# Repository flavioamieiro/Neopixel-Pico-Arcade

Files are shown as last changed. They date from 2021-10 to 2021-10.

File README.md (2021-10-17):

The Neopixel Pico Arcade is a simple mini game with LEDs for a screen and
controlled by an NES controller.

It's built around the [RP2040
stamp](https://www.solder.party/rp2040_stamp_datasheet.pdf) designed by
@arturo182.

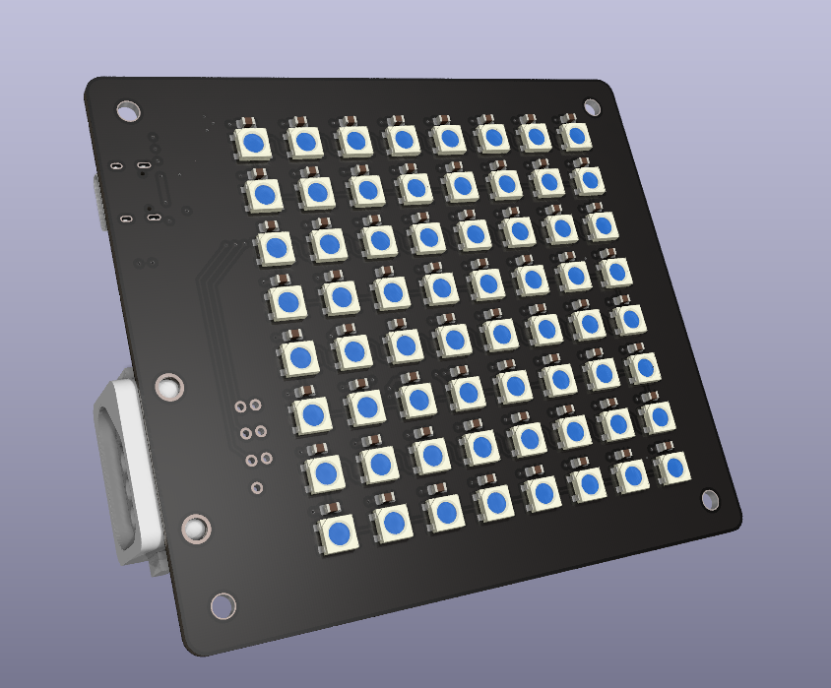
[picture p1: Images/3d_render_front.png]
PCB 3D render front

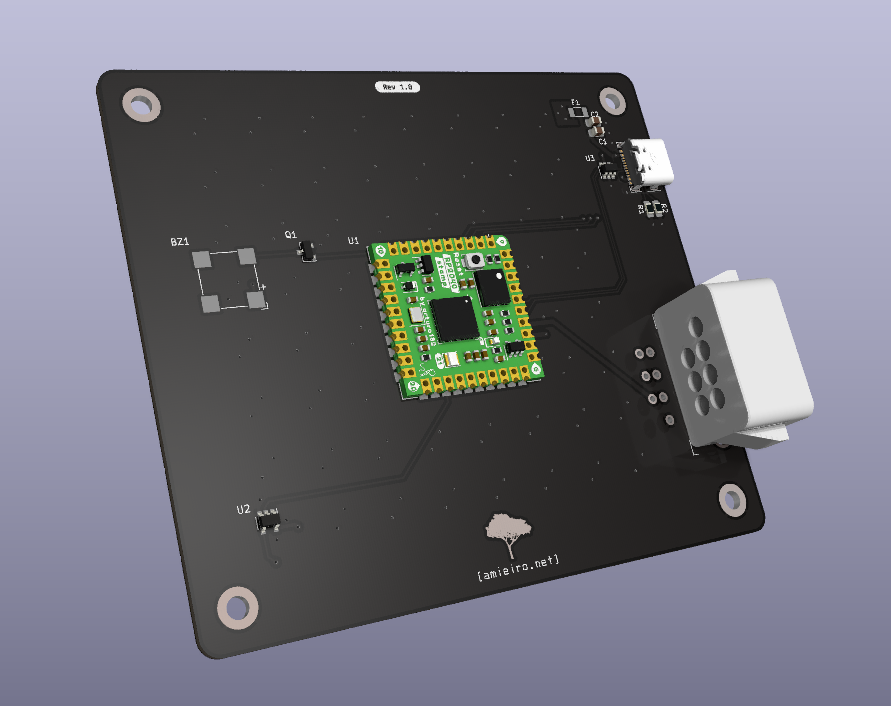
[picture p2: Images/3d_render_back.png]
PCB 3D render back


This source describes Open Hardware and is licensed under the CERN-OHL-S v2.
You may redistribute and modify this source and make products using it under
the terms of the [CERN-OHL-S v2](https://ohwr.org/cern_ohl_s_v2.txt).

Source location: https://github.com/flavioamieiro/Neopixel-Pico-Arcade

As per CERN-OHL-S v2 section 4, should You produce hardware based on this
source, You must where practicable maintain the Source Location visible on the
external case of the Gizmo or other products you make using this source.

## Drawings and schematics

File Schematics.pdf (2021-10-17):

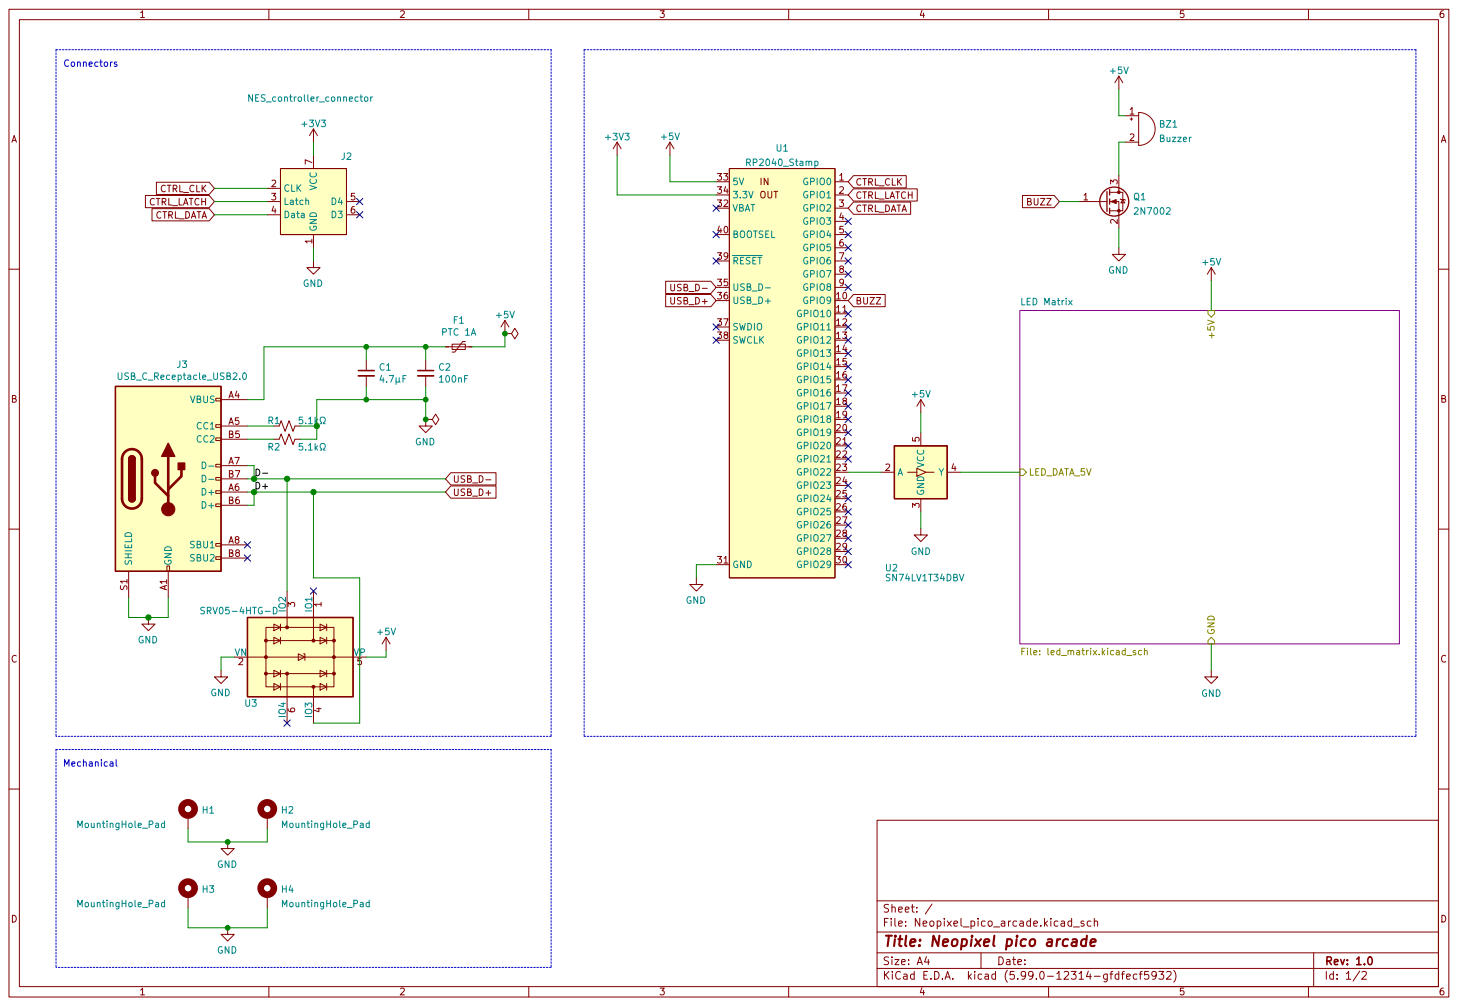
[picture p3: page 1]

File: Neopixel_pico_arcade.kicad_sch Sheet: /
Id: 1/2 Title: Neopixel pico arcade

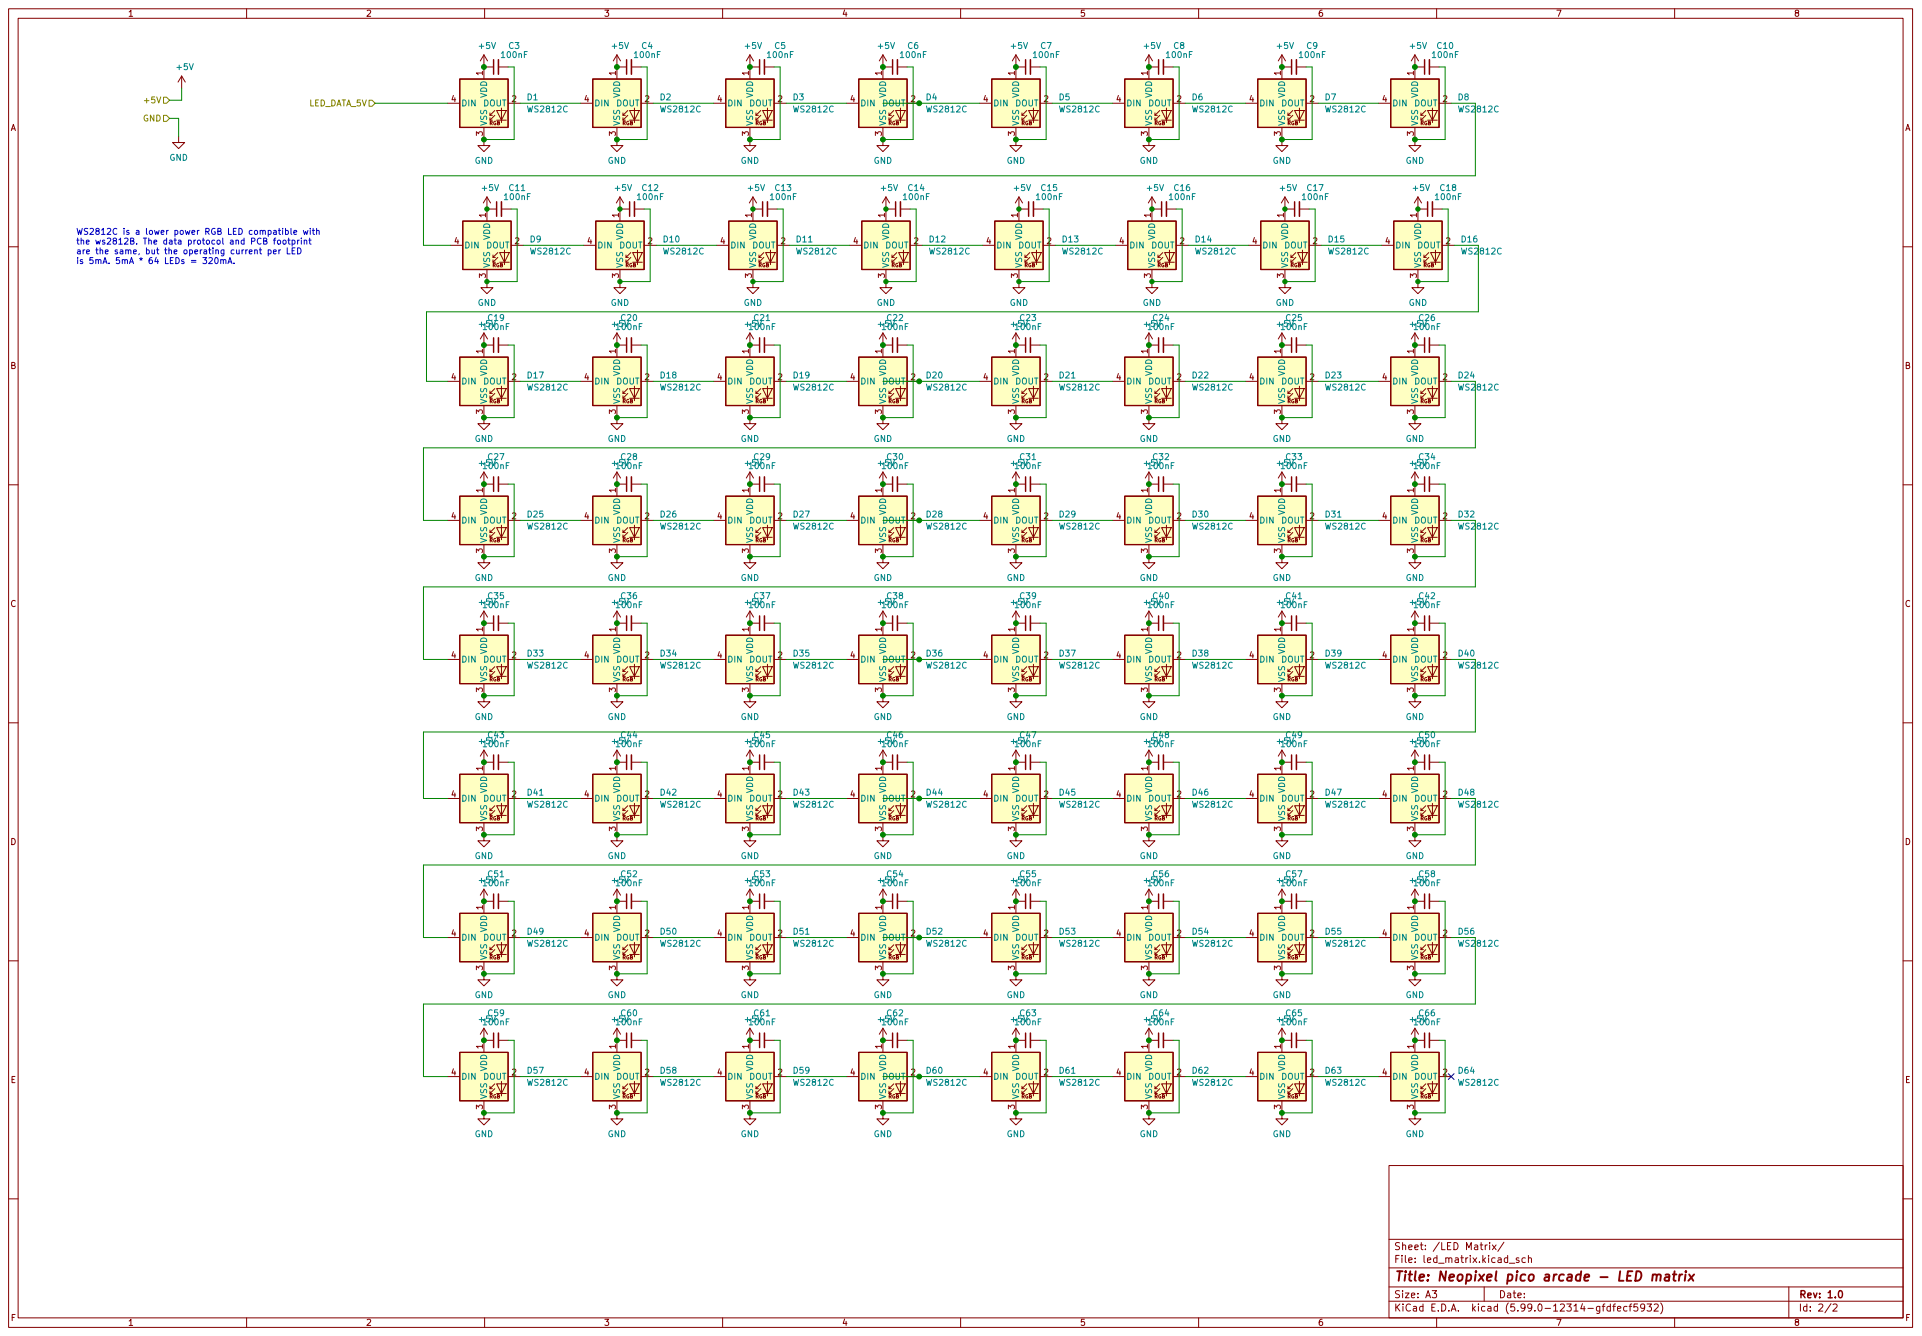
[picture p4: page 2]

LED_DATA_5V +5V GND WS2812C is a lower power RGB LED compatible with

the ws2812B. The data protocol and PCB footprint
are the same, but the operating current per LED
is 5mA. 5mA * 64 LEDs = 320mA.

File: led_matrix.kicad_sch Sheet: /LED Matrix/
Id: 2/2 Title: Neopixel pico arcade - LED matrix

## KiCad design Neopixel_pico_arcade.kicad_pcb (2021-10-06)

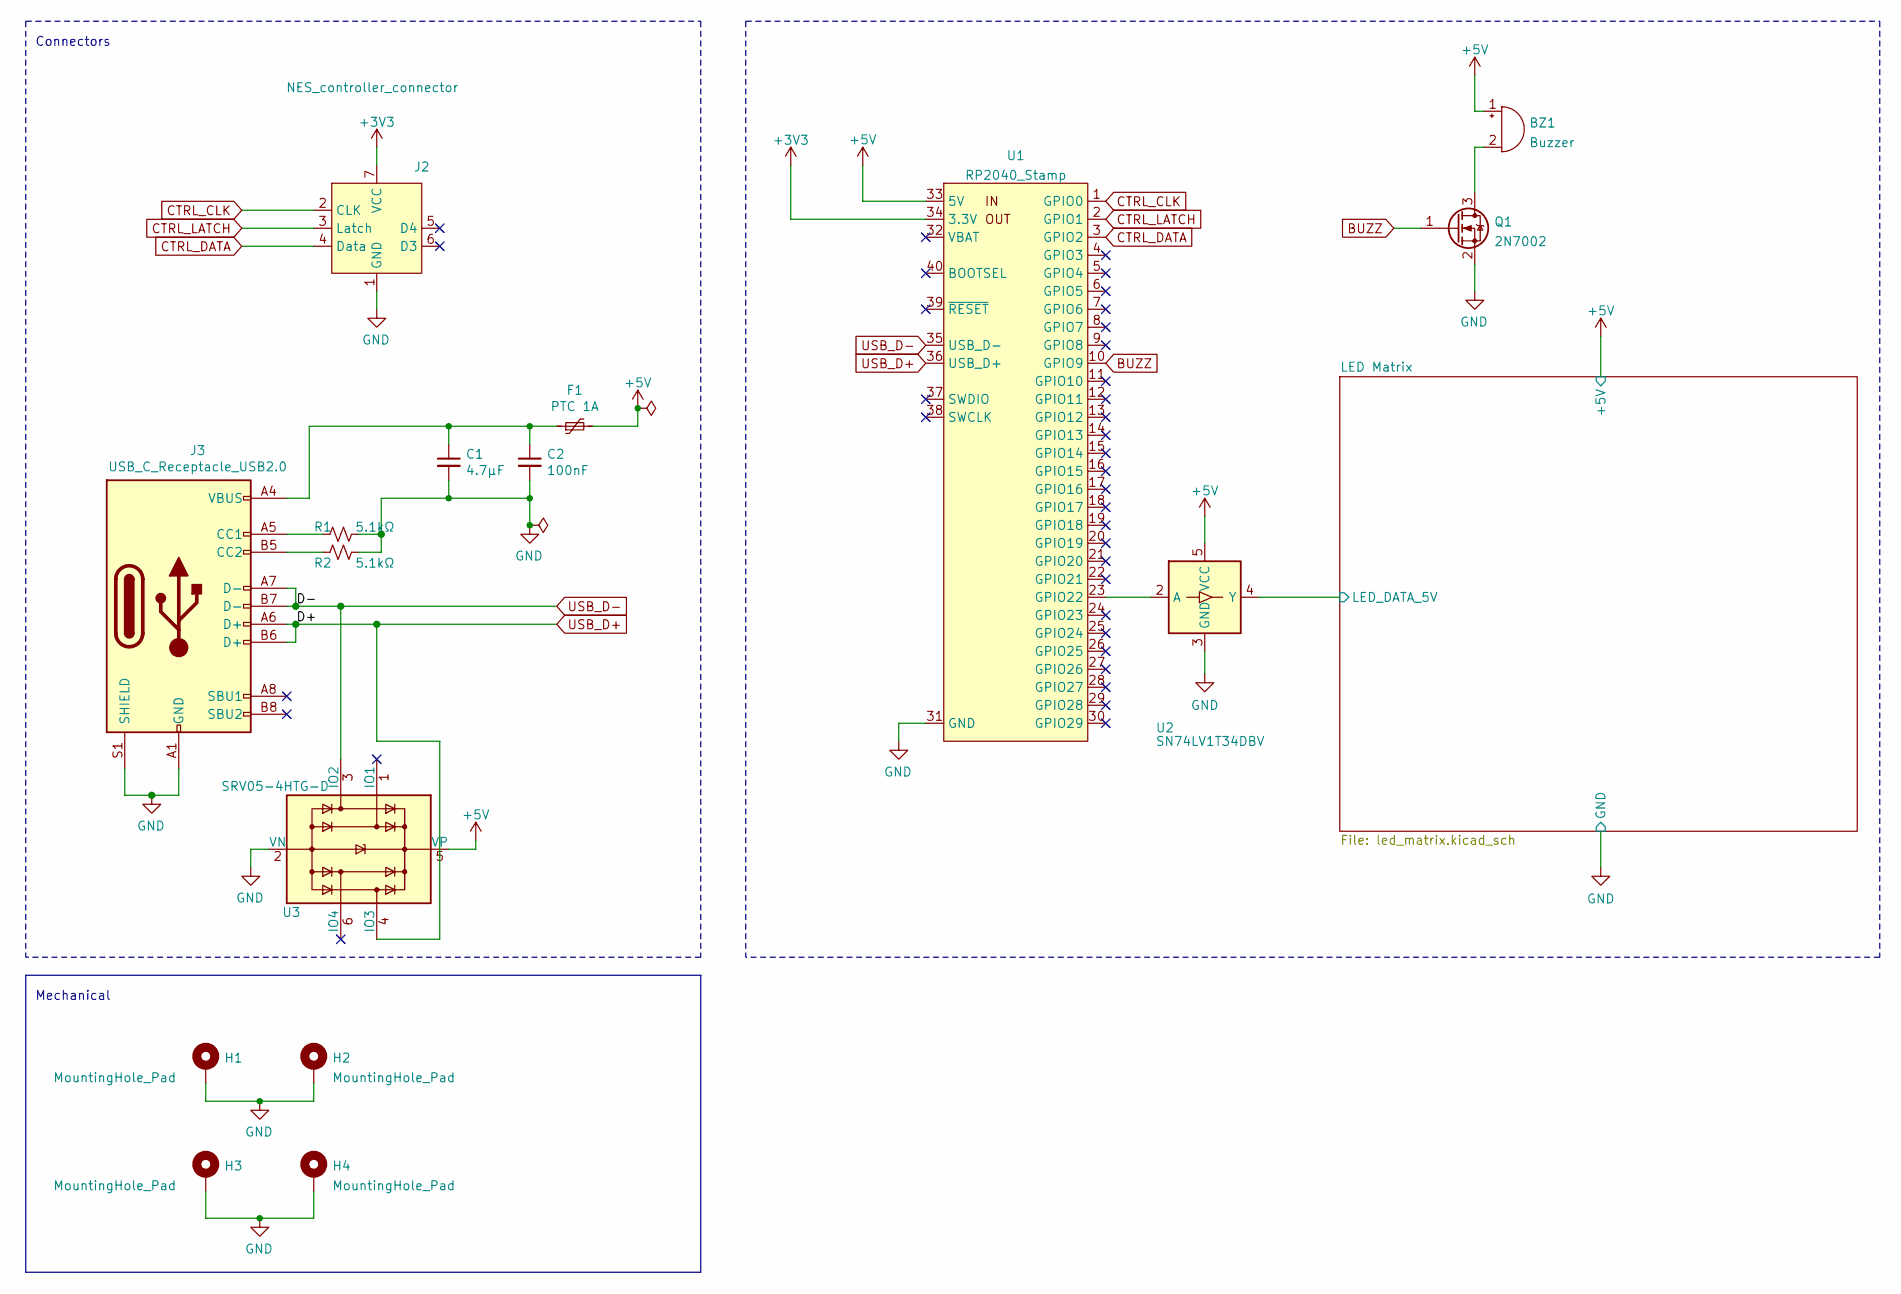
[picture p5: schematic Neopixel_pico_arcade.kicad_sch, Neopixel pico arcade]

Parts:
BZ1: Buzzer; MagneticBuzzer_CUI_CMT-8504-100-SMT
C1: 4.7µF; C_0805_2012Metric_Pad1.18x1.45mm_HandSolder
C2: 100nF; C_0805_2012Metric_Pad1.18x1.45mm_HandSolder
F1: PTC 1A; Belfuse_0ZCJ
H1, H2, H3, H4: MountingHole_Pad; MountingHole_3.2mm_M3_ISO7380_Pad_TopOnly
J2: NES_controller_connector; NES_Controller_connector
J3: USB_C_Receptacle_USB2.0; USB_C_Receptacle_USB_2_GTC_USB4105
Q1: 2N7002; SOT-23
R1, R2: 5.1kΩ; R_0805_2012Metric_Pad1.20x1.40mm_HandSolder
U1: RP2040_Stamp; RP2040_Stamp_SMD
U2: SN74LV1T34DBV; SOT-23-5
U3: SRV05-4HTG-D; SOT-23-6; MPN SRV05-4HTG-D

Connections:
+3V3: J2.7 (VCC), U1.34 (3.3V)
+5V: BZ1.1 (-), F1.2, U1.33 (5V), U2.5 (VCC), U3.5 (VP); also elsewhere on the board
/LED Matrix/LED_DATA_5V: U2.4 (Y); also elsewhere on the board
BUZZ: Q1.1 (G), U1.10 (GPIO9)
CTRL_CLK: J2.2 (CLK), U1.1 (GPIO0)
CTRL_DATA: J2.4 (Data), U1.3 (GPIO2)
CTRL_LATCH: J2.3 (Latch), U1.2 (GPIO1)
GND: C1.2, C2.2, H1.1, H2.1, H3.1, H4.1, J2.1 (GND), J3.A1 (GND), J3.A12 (GND), J3.B1 (GND), J3.B12 (GND), J3.S1 (SHIELD), Q1.2 (S), R1.2, R2.2, U1.31 (GND), U2.3 (GND), U3.2 (VN); also elsewhere on the board
unnamed: BZ1.2 (+), Q1.3 (D)
unnamed: C1.1, C2.1, F1.1, J3.A4 (VBUS), J3.A9 (VBUS), J3.B4 (VBUS), J3.B9 (VBUS)
unnamed: J3.A5 (CC1), R1.1
unnamed: J3.B5 (CC2), R2.1
unnamed: U1.23 (GPIO22), U2.2 (A)
USB_D+: J3.A6 (D+), J3.B6 (D+), U1.36 (USB_D+), U3.4 (IO3)
USB_D-: J3.A7 (D-), J3.B7 (D-), U1.35 (USB_D-), U3.3 (IO2)

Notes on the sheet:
Mechanical
Connectors

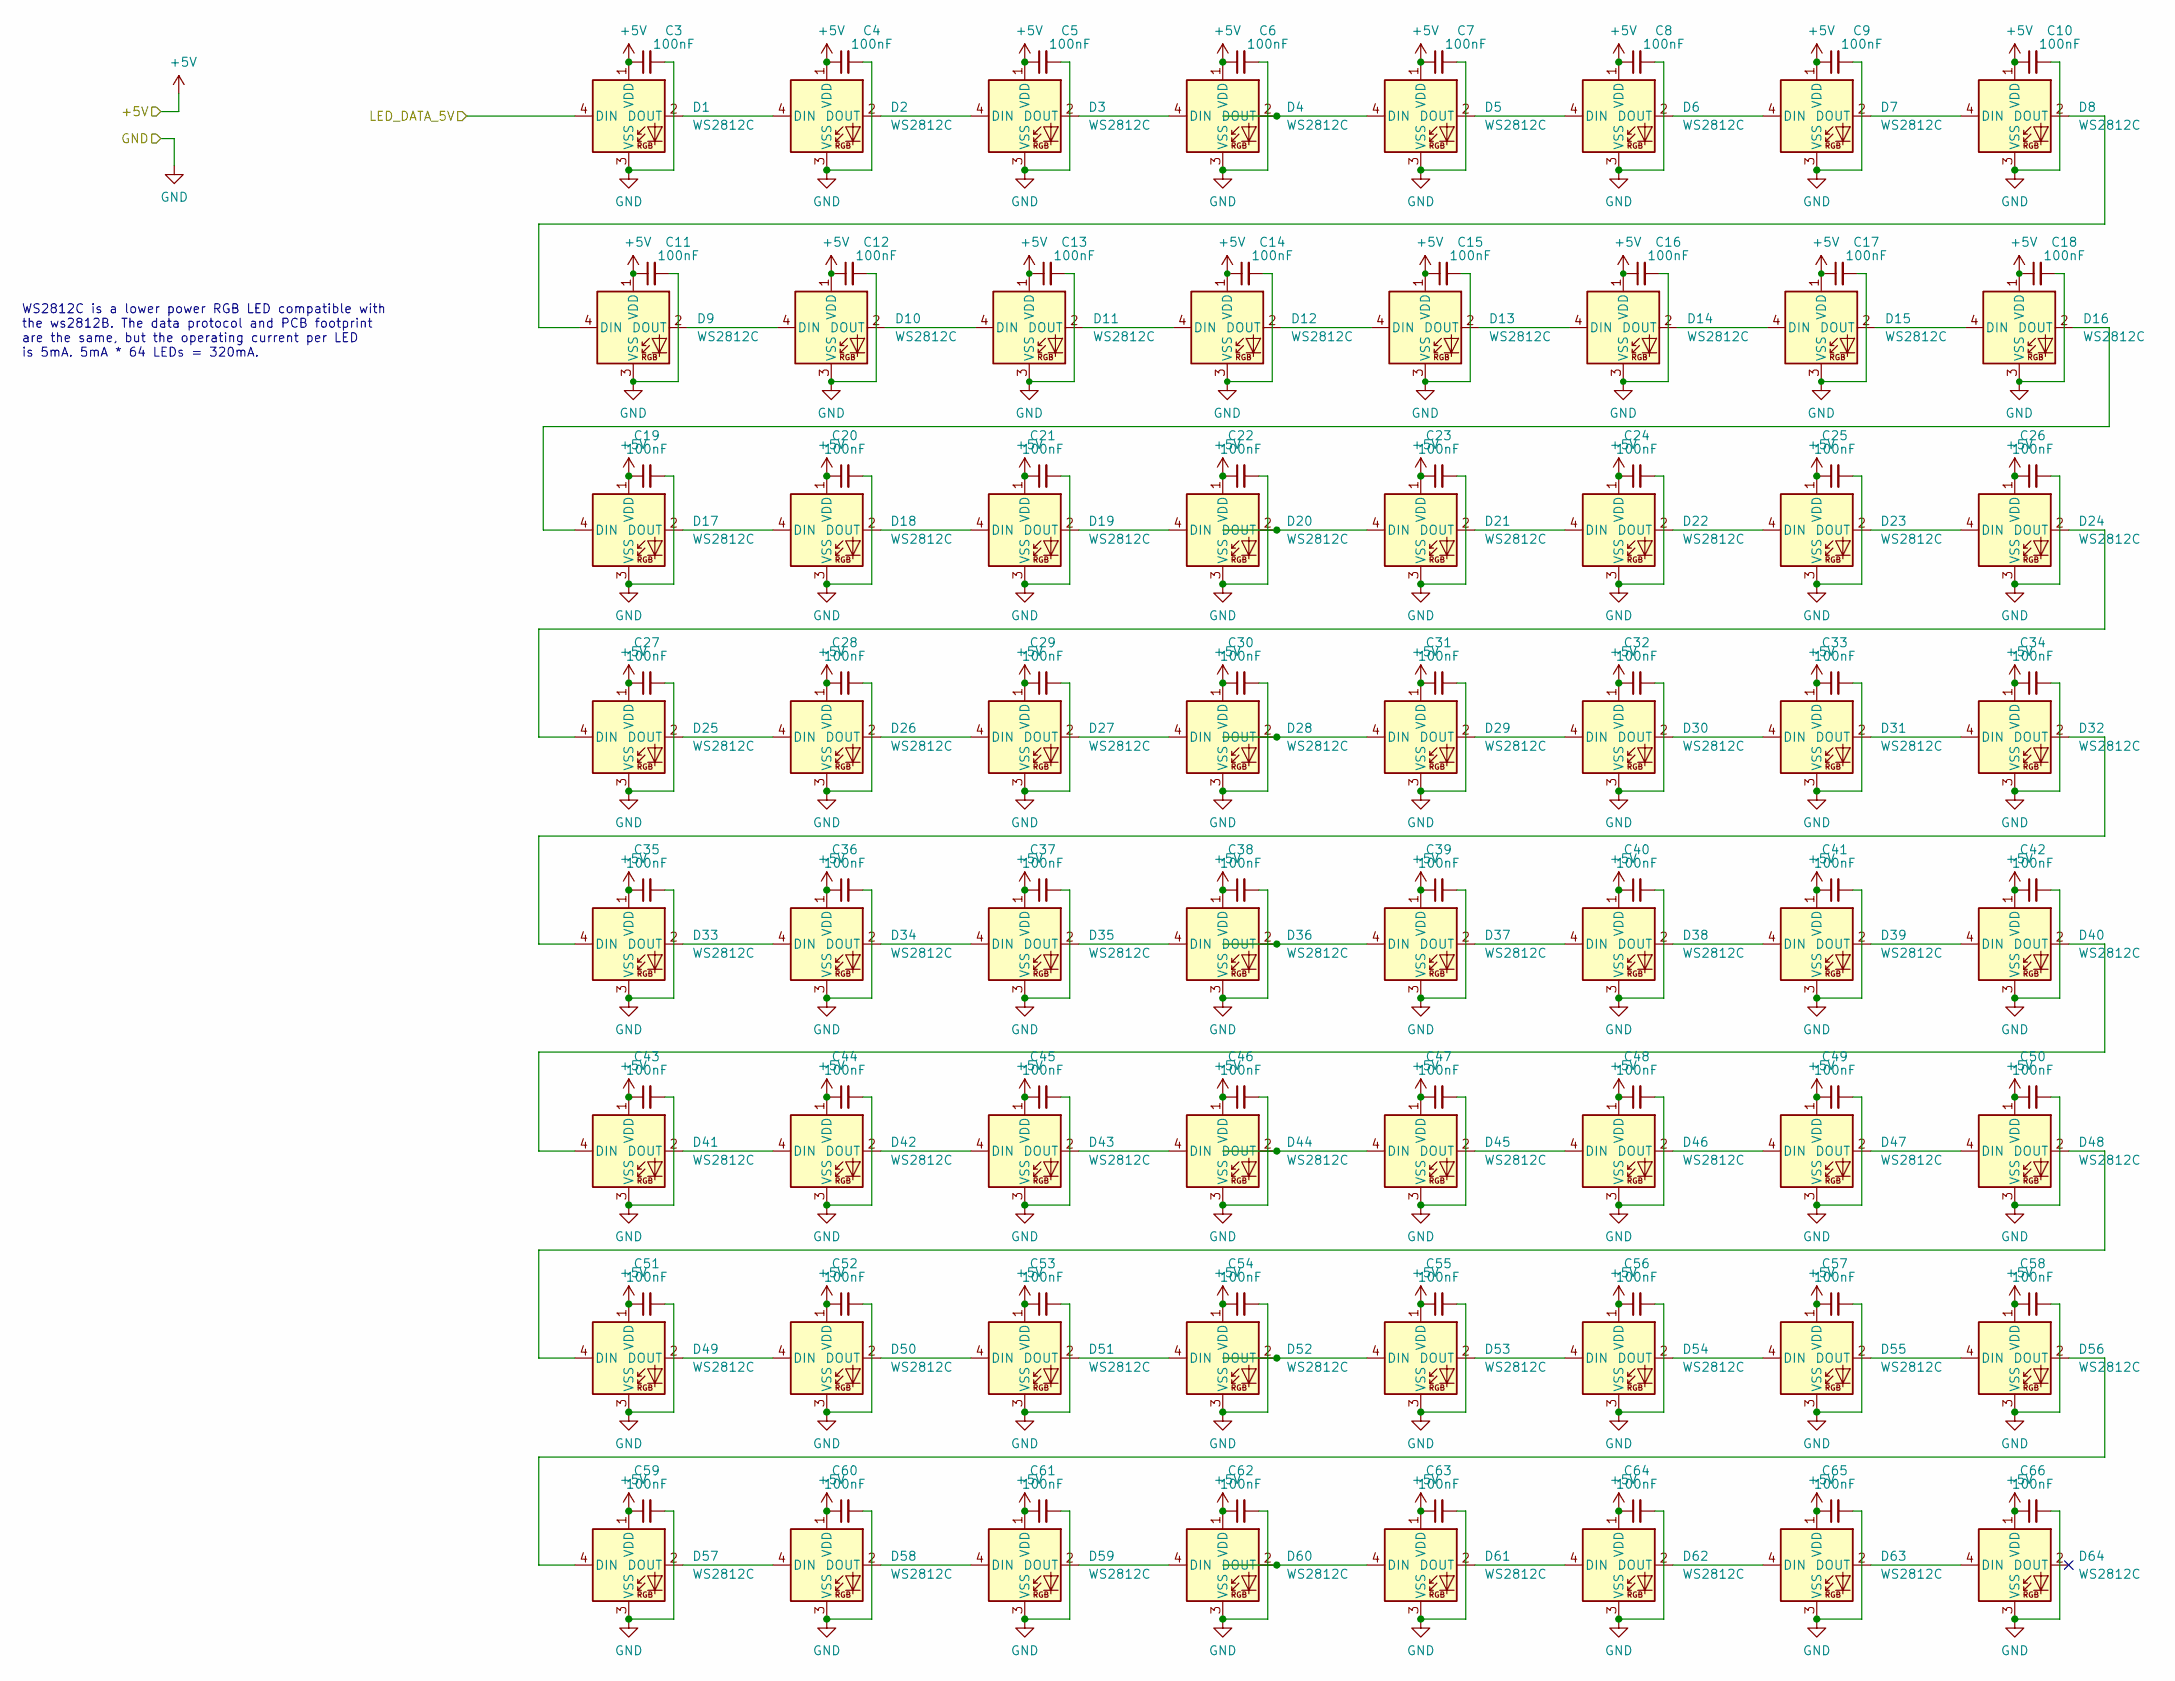
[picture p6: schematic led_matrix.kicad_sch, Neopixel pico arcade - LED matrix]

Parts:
C3, C4, C5, C6, C7, C8, C9, C10, C11, C12, C13, C14, C15, C16, C17, C18, C19, C20, C21, C22, C23, C24, C25, C26, C27, C28, C29, C30, C31, C32, C33, C34, C35, C36, C37, C38, C39, C40, C41, C42, C43, C44, C45, C46, C47, C48, C49, C50, C51, C52, C53, C54, C55, C56, C57, C58, C59, C60, C61, C62, C63, C64, C65, C66: 100nF; C_0805_hidden_silkscreen_2012Metric_Pad1.18x1.45mm_HandSold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; LCSC C49678
D1, D2, D3, D4, D5, D6, D7, D8, D9, D10, D11, D12, D13, D14, D15, D16, D17, D18, D19, D20, D21, D22, D23, D24, D25, D26, D27, D28, D29, D30, D31, D32, D33, D34, D35, D36, D37, D38, D39, D40, D41, D42, D43, D44, D45, D46, D47, D48, D49, D50, D51, D52, D53, D54, D55, D56, D57, D58, D59, D60, D61, D62, D63, D64: WS2812C; LED_WS2812C_HIDDEN_SILKSCREEN_5.0x5.0mm_P3.2mm; LCSC C114587

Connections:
+5V: C3.1, C4.1, C5.1, C6.1, C7.1, C8.1, C9.1, C10.1, C11.1, C12.1, C13.1, C14.1, C15.1, C16.1, C17.1, C18.1, C19.1, C20.1, C21.1, C22.1, C23.1, C24.1, C25.1, C26.1, C27.1, C28.1, C29.1, C30.1, C31.1, C32.1, C33.1, C34.1, C35.1, C36.1, C37.1, C38.1, C39.1, C40.1, C41.1, C42.1, C43.1, C44.1, C45.1, C46.1, C47.1, C48.1, C49.1, C50.1, C51.1, C52.1, C53.1, C54.1, C55.1, C56.1, C57.1, C58.1, C59.1, C60.1, C61.1, C62.1, C63.1, C64.1, C65.1, C66.1, D1.1 (VDD), D2.1 (VDD), D3.1 (VDD), D4.1 (VDD), D5.1 (VDD), D6.1 (VDD), D7.1 (VDD), D8.1 (VDD), D9.1 (VDD), D10.1 (VDD), D11.1 (VDD), D12.1 (VDD), D13.1 (VDD), D14.1 (VDD), D15.1 (VDD), D16.1 (VDD), D17.1 (VDD), D18.1 (VDD), D19.1 (VDD), D20.1 (VDD), D21.1 (VDD), D22.1 (VDD), D23.1 (VDD), D24.1 (VDD), D25.1 (VDD), D26.1 (VDD), D27.1 (VDD), D28.1 (VDD), D29.1 (VDD), D30.1 (VDD), D31.1 (VDD), D32.1 (VDD), D33.1 (VDD), D34.1 (VDD), D35.1 (VDD), D36.1 (VDD), D37.1 (VDD), D38.1 (VDD), D39.1 (VDD), D40.1 (VDD), D41.1 (VDD), D42.1 (VDD), D43.1 (VDD), D44.1 (VDD), D45.1 (VDD), D46.1 (VDD), D47.1 (VDD), D48.1 (VDD), D49.1 (VDD), D50.1 (VDD), D51.1 (VDD), D52.1 (VDD), D53.1 (VDD), D54.1 (VDD), D55.1 (VDD), D56.1 (VDD), D57.1 (VDD), D58.1 (VDD), D59.1 (VDD), D60.1 (VDD), D61.1 (VDD), D62.1 (VDD), D63.1 (VDD), D64.1 (VDD); also elsewhere on the board
/LED Matrix/LED_DATA_5V: D1.4 (DIN); also elsewhere on the board
GND: C3.2, C4.2, C5.2, C6.2, C7.2, C8.2, C9.2, C10.2, C11.2, C12.2, C13.2, C14.2, C15.2, C16.2, C17.2, C18.2, C19.2, C20.2, C21.2, C22.2, C23.2, C24.2, C25.2, C26.2, C27.2, C28.2, C29.2, C30.2, C31.2, C32.2, C33.2, C34.2, C35.2, C36.2, C37.2, C38.2, C39.2, C40.2, C41.2, C42.2, C43.2, C44.2, C45.2, C46.2, C47.2, C48.2, C49.2, C50.2, C51.2, C52.2, C53.2, C54.2, C55.2, C56.2, C57.2, C58.2, C59.2, C60.2, C61.2, C62.2, C63.2, C64.2, C65.2, C66.2, D1.3 (VSS), D2.3 (VSS), D3.3 (VSS), D4.3 (VSS), D5.3 (VSS), D6.3 (VSS), D7.3 (VSS), D8.3 (VSS), D9.3 (VSS), D10.3 (VSS), D11.3 (VSS), D12.3 (VSS), D13.3 (VSS), D14.3 (VSS), D15.3 (VSS), D16.3 (VSS), D17.3 (VSS), D18.3 (VSS), D19.3 (VSS), D20.3 (VSS), D21.3 (VSS), D22.3 (VSS), D23.3 (VSS), D24.3 (VSS), D25.3 (VSS), D26.3 (VSS), D27.3 (VSS), D28.3 (VSS), D29.3 (VSS), D30.3 (VSS), D31.3 (VSS), D32.3 (VSS), D33.3 (VSS), D34.3 (VSS), D35.3 (VSS), D36.3 (VSS), D37.3 (VSS), D38.3 (VSS), D39.3 (VSS), D40.3 (VSS), D41.3 (VSS), D42.3 (VSS), D43.3 (VSS), D44.3 (VSS), D45.3 (VSS), D46.3 (VSS), D47.3 (VSS), D48.3 (VSS), D49.3 (VSS), D50.3 (VSS), D51.3 (VSS), D52.3 (VSS), D53.3 (VSS), D54.3 (VSS), D55.3 (VSS), D56.3 (VSS), D57.3 (VSS), D58.3 (VSS), D59.3 (VSS), D60.3 (VSS), D61.3 (VSS), D62.3 (VSS), D63.3 (VSS), D64.3 (VSS); also elsewhere on the board
unnamed: D1.2 (DOUT), D2.4 (DIN)
unnamed: D2.2 (DOUT), D3.4 (DIN)
unnamed: D3.2 (DOUT), D4.4 (DIN)
unnamed: D4.2 (DOUT), D5.4 (DIN)
unnamed: D5.2 (DOUT), D6.4 (DIN)
unnamed: D6.2 (DOUT), D7.4 (DIN)
unnamed: D7.2 (DOUT), D8.4 (DIN)
unnamed: D8.2 (DOUT), D9.4 (DIN)
unnamed: D10.2 (DOUT), D11.4 (DIN)
unnamed: D9.2 (DOUT), D10.4 (DIN)
unnamed: D11.2 (DOUT), D12.4 (DIN)
unnamed: D12.2 (DOUT), D13.4 (DIN)
unnamed: D13.2 (DOUT), D14.4 (DIN)
unnamed: D14.2 (DOUT), D15.4 (DIN)
unnamed: D15.2 (DOUT), D16.4 (DIN)
unnamed: D16.2 (DOUT), D17.4 (DIN)
unnamed: D17.2 (DOUT), D18.4 (DIN)
unnamed: D18.2 (DOUT), D19.4 (DIN)
unnamed: D19.2 (DOUT), D20.4 (DIN)
unnamed: D20.2 (DOUT), D21.4 (DIN)
unnamed: D21.2 (DOUT), D22.4 (DIN)
unnamed: D22.2 (DOUT), D23.4 (DIN)
unnamed: D23.2 (DOUT), D24.4 (DIN)
unnamed: D24.2 (DOUT), D25.4 (DIN)
unnamed: D25.2 (DOUT), D26.4 (DIN)
unnamed: D26.2 (DOUT), D27.4 (DIN)
unnamed: D27.2 (DOUT), D28.4 (DIN)
unnamed: D28.2 (DOUT), D29.4 (DIN)
unnamed: D29.2 (DOUT), D30.4 (DIN)
unnamed: D30.2 (DOUT), D31.4 (DIN)
unnamed: D31.2 (DOUT), D32.4 (DIN)
unnamed: D32.2 (DOUT), D33.4 (DIN)
unnamed: D33.2 (DOUT), D34.4 (DIN)
unnamed: D34.2 (DOUT), D35.4 (DIN)
unnamed: D35.2 (DOUT), D36.4 (DIN)
unnamed: D36.2 (DOUT), D37.4 (DIN)
unnamed: D37.2 (DOUT), D38.4 (DIN)
unnamed: D38.2 (DOUT), D39.4 (DIN)
unnamed: D39.2 (DOUT), D40.4 (DIN)
unnamed: D40.2 (DOUT), D41.4 (DIN)
unnamed: D41.2 (DOUT), D42.4 (DIN)
unnamed: D42.2 (DOUT), D43.4 (DIN)
unnamed: D43.2 (DOUT), D44.4 (DIN)
unnamed: D44.2 (DOUT), D45.4 (DIN)
unnamed: D45.2 (DOUT), D46.4 (DIN)
unnamed: D46.2 (DOUT), D47.4 (DIN)
unnamed: D47.2 (DOUT), D48.4 (DIN)
unnamed: D48.2 (DOUT), D49.4 (DIN)
unnamed: D49.2 (DOUT), D50.4 (DIN)
unnamed: D50.2 (DOUT), D51.4 (DIN)
unnamed: D51.2 (DOUT), D52.4 (DIN)
unnamed: D52.2 (DOUT), D53.4 (DIN)
unnamed: D53.2 (DOUT), D54.4 (DIN)
unnamed: D54.2 (DOUT), D55.4 (DIN)
unnamed: D55.2 (DOUT), D56.4 (DIN)
unnamed: D56.2 (DOUT), D57.4 (DIN)
unnamed: D57.2 (DOUT), D58.4 (DIN)
unnamed: D58.2 (DOUT), D59.4 (DIN)
unnamed: D59.2 (DOUT), D60.4 (DIN)
unnamed: D60.2 (DOUT), D61.4 (DIN)
unnamed: D61.2 (DOUT), D62.4 (DIN)
unnamed: D62.2 (DOUT), D63.4 (DIN)
unnamed: D63.2 (DOUT), D64.4 (DIN)

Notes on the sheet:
WS2812C is a lower power RGB LED compatible with the ws2812B. The data protocol and PCB footprint are the same, but the operating current per LED is 5mA. 5mA * 64 LEDs = 320mA.

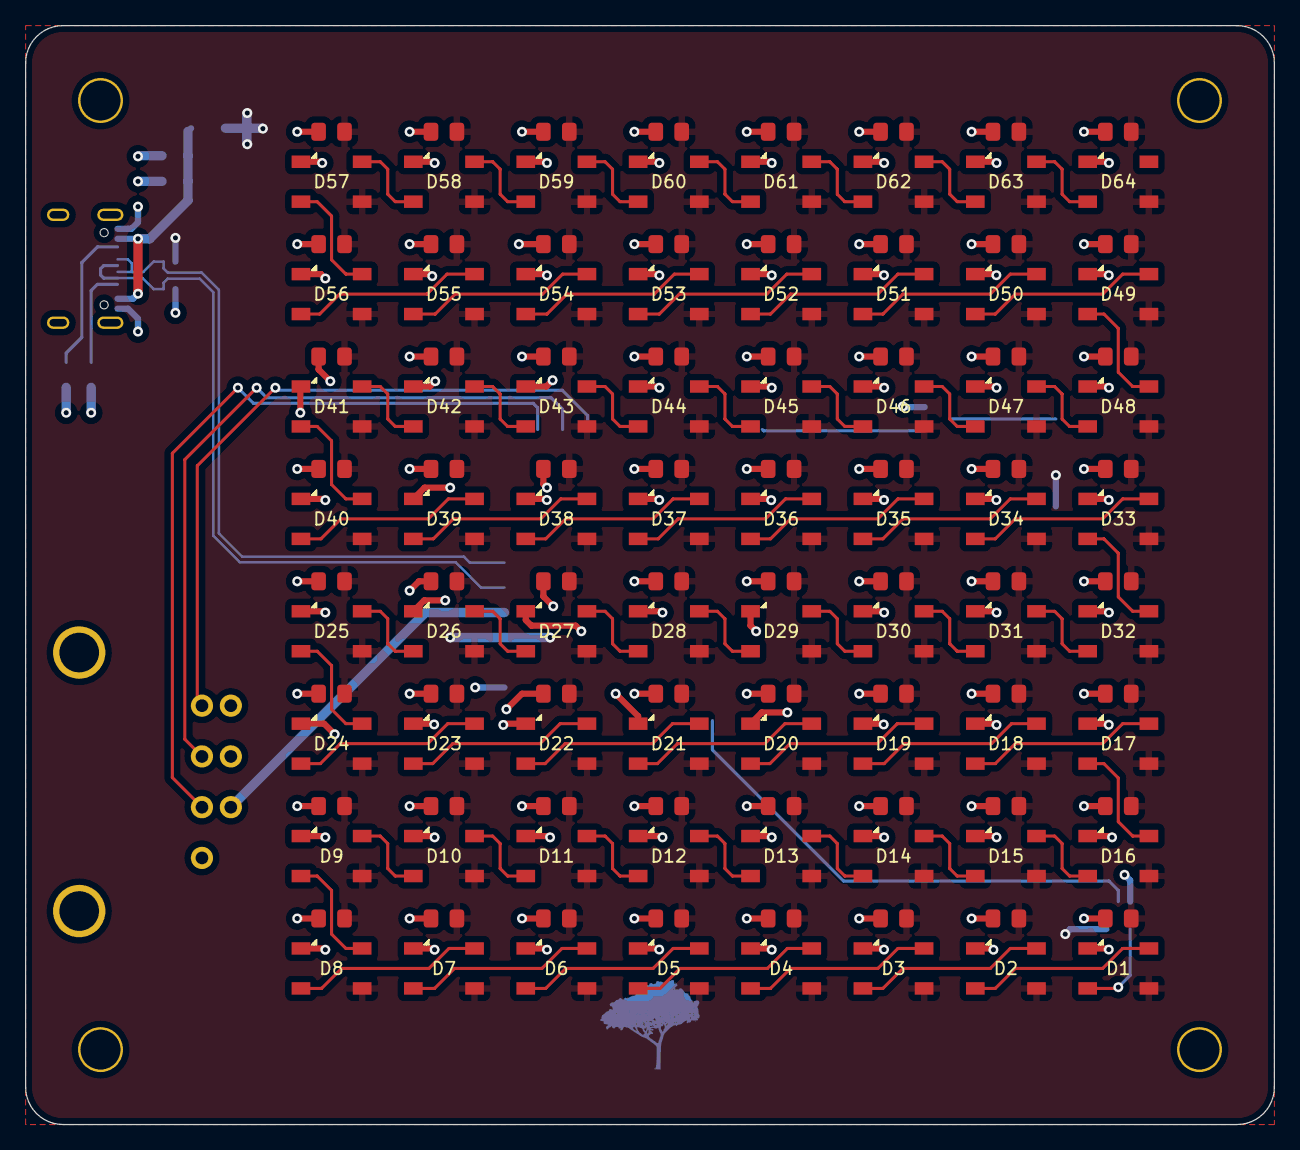
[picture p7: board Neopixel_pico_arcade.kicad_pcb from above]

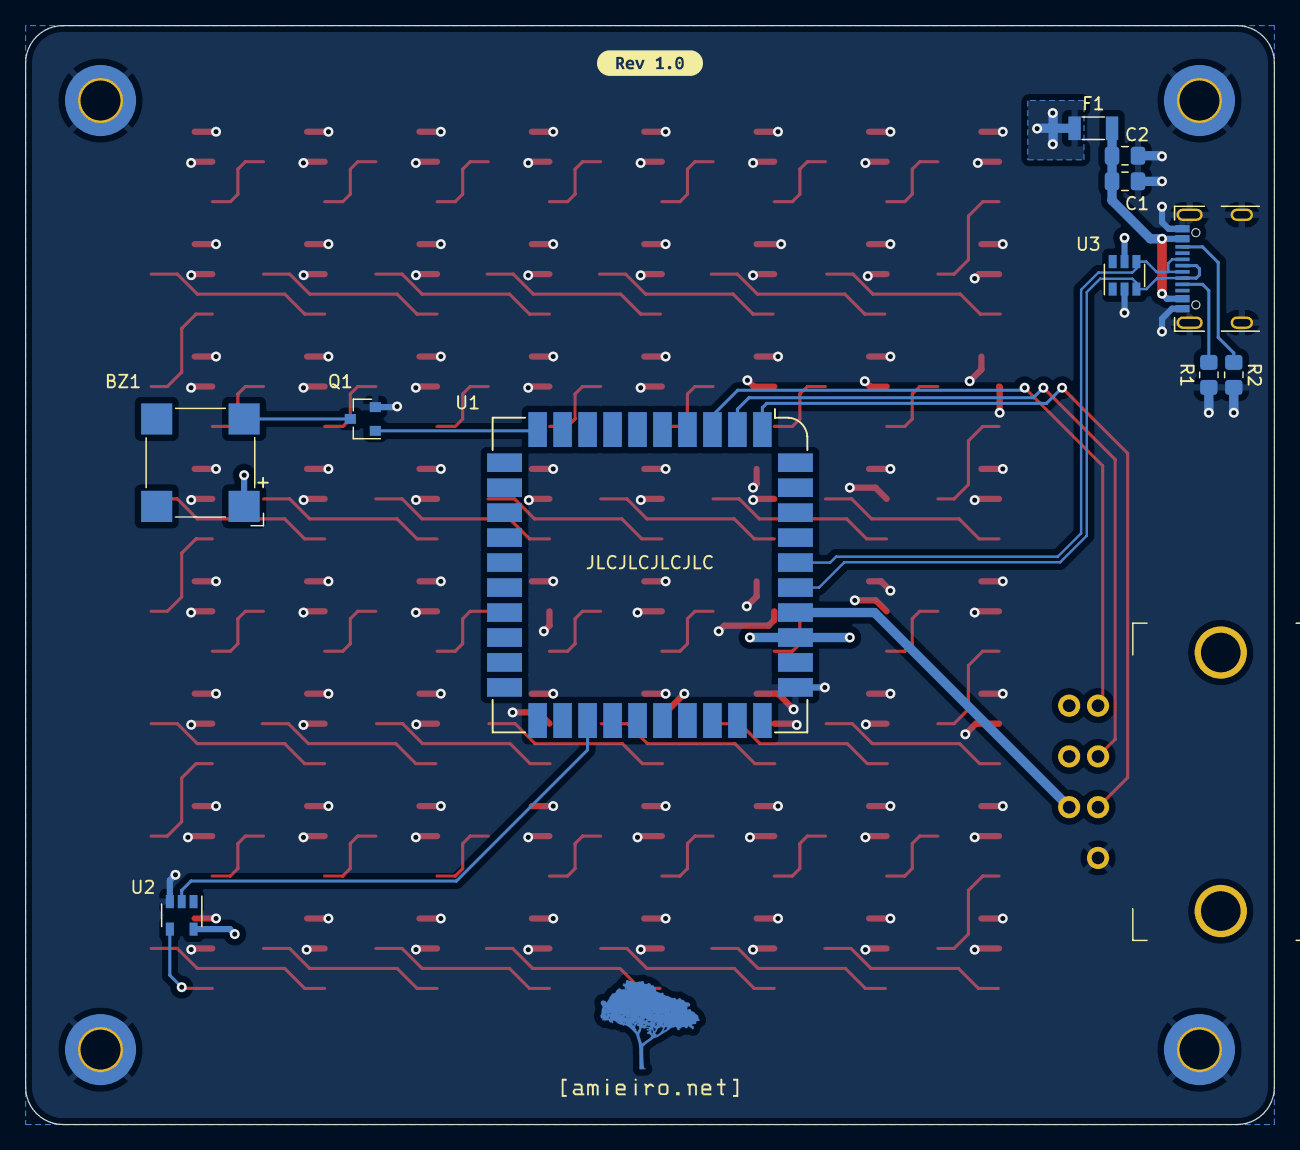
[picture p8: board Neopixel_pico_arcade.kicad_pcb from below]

Board: 4 copper layers, 100.0 x 88.0 mm, 147 parts (17 on the bottom side), 78 nets.

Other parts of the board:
Ref**: Val**; url_bsilks
Ref**#2: Val**; ipe_logo
kibuzzard-615E1A5A: G***; kibuzzard-615E1A5A

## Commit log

2021-09-17 Initial commit with incomplete schematics
    This commit includes the start point for the schematics (still missing
    mainly the boost converter block) and the schematic symbol and footprint
    for the RP2040 stamp[1].
    [1]: https://github.com/solderparty/rp2040_stamp_footprints
    [RP2040_stamp_NES_LED_matrix.kicad_pcb, RP2040_stamp_NES_LED_matrix.kicad_sch, led_matrix.kicad_sch]
2021-09-18 Removes boost converter placeholder since it won't be possible to use it
    The stamp can only provide 500mA@3.3v, which gives us 1.65W. Assuming a
    85% efficiency of the boost regulator, that would give us 1.4W on the
    output, or 280mA@5V. We need 320mA to run the 64 WS2812C, so it doesn't
    seem to be possible to run these from a LiPO battery unless we rely on
    the software never running all the LEDs at full brightness, but that
    doesn't seem like a reliable option.
    We'll still use the WS2812C instead of the B for the lower power
    consumption, though. Since we don't need a lot of brightness, running
    the matrix with 320mA should make it possible for the whole thing to run
    from a standard USB connect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
    [RP2040_stamp_NES_LED_matrix.kicad_sch, led_matrix.kicad_sch]
2021-09-19 Renames the project to Neopixel pico arcade
    [Neopixel_pico_arcade.kicad_pcb, Neopixel_pico_arcade.kicad_sch]
2021-09-19 Adds bulk capacitance for USB power
    USB devices should be limited to at most 10µF capacitance to keep inrush
    current under the specified limits.
    [Neopixel_pico_arcade.kicad_sch]
2021-09-21 Adds jumpers to latch and clock lines to make rework easier
    I've switched those two pins a few times already during prototyping.
    With the normally closed jumpers it will be easier to swap them if I
    make a mistake while laying out the board.
    [Neopixel_pico_arcade.kicad_sch]
2021-09-21 Adds a buzzer to the schematics
    We needed a way to generate some kind of annoying sound :)
    [Neopixel_pico_arcade.kicad_sch]
2021-09-29 Annotates components on schematics
    [Neopixel_pico_arcade.kicad_sch, led_matrix.kicad_sch]
2021-09-29 Align elements to grid
    [Neopixel_pico_arcade.kicad_sch]
2021-09-29 Changes +5v symbols
    These were copied from another project and Kicad included references to
    that library.
    [Neopixel_pico_arcade.kicad_sch]
2021-09-29 Fixes ERC errors on top level sheet
    [Neopixel_pico_arcade.kicad_sch]
2021-09-29 Fixes ERC errors in the LED matrix schematics
    [led_matrix.kicad_sch]
2021-09-29 Associates most components with footprints
    We're still missing the NES controller connector footprint.
    [Neopixel_pico_arcade.kicad_sch]
2021-09-29 Adds custom schematic symbol for NES controller connector
    [Neopixel_pico_arcade.kicad_sch]
2021-09-30 Adds footprint for the NES controller connector
    [Neopixel_pico_arcade.kicad_sch]
2021-09-30 Adds 3d model for NES connector
    Derived from a .stl file downloaded from https://www.thingiverse.com/thing:1753655
2021-09-30 Associates capacitors to the correct footprint
    [Neopixel_pico_arcade.kicad_sch, led_matrix.kicad_sch]
2021-09-30 Reassociates RP2040 stamp to the footprint
    [Neopixel_pico_arcade.kicad_sch]
2021-10-03 Adds footprint for GTC USB4105 USB type C connector
    This connector is for USB2.0 and power delivery only.
    Datasheet is available at https://gct.co/files/specs/usb4105-spec.pdf
    and drawings at https://gct.co/files/drawings/usb4105.pdf
    [Neopixel_pico_arcade.kicad_sch]
2021-10-03 Adds project name and revision to schematics
    [Neopixel_pico_arcade.kicad_sch, led_matrix.kicad_sch]
2021-10-03 Adds kicad_prl to gitignore
    This file stores local settings[1], so it should not be tracked by git.
    [1]: https://forum.kicad.info/t/new-project-file-format/23705
2021-10-03 Adds mounting holes to schematics
    These are connected to ground, but will have pads only on once the
    bottom so the exposed pad on top doesn't interfere with the face where
    the LEDs are.
    [Neopixel_pico_arcade.kicad_sch]
2021-10-03 Adds basic PCB file with board outline
    [Neopixel_pico_arcade.kicad_pcb]
2021-10-03 Switches SWD connector to SDM pin headers
    [Neopixel_pico_arcade.kicad_sch]
2021-10-03 Moves bottom side components roughly into place
    The NES connector will still need to move to make space for the LEDs.
    This probably means the PCB will need to grow.
    [Neopixel_pico_arcade.kicad_pcb]
2021-10-03 Arranges LEDs in an ordered matrix
    [Neopixel_pico_arcade.kicad_pcb]
2021-10-03 Arranges capacitors in the LED matrix
    [Neopixel_pico_arcade.kicad_pcb]
2021-10-03 Uses a copy of the built-in WS2812B footprint but with hidden silkscreen
    Since this will be the screen, it's better to have no visible silkscreen.
    [Neopixel_pico_arcade.kicad_pcb, Neopixel_pico_arcade.kicad_sch, led_matrix.kicad_sch]
2021-10-03 Adds a copy of the built-in 0805 capacitor footprint with no silkscreen
    For the same reason we hid the LED silkscreen.
    [Neopixel_pico_arcade.kicad_pcb, Neopixel_pico_arcade.kicad_sch, led_matrix.kicad_sch]
2021-10-03 Fixes PCB thickness
    When changing to a 4-layer PCB in the setup it didn't adapt the overall
    thickness to 1.6mm.
    [Neopixel_pico_arcade.kicad_pcb]
2021-10-03 Adjusts LED matrix placement
    Because of the NES connector and it's through hole leads it's really
    hard to keep it symmetric while keeping it under 100mm x 100mm*. The
    solution I found is to keep the spacing between the LEDs and the edges
    the same in all but the side where the connectors are. This would
    probably be better in the bottom, but then the cables would have nowhere
    to exit from.
    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
    [Neopixel_pico_arcade.kicad_pcb]
2021-10-03 Fixes LED ordering in the matrix
    After routing some of the LED data pins, I noticed some of the last rows
    were wrong.
    [Neopixel_pico_arcade.kicad_pcb]
2021-10-03 Routes data pins between the LEDs
    [Neopixel_pico_arcade.kicad_pcb]
2021-10-03 First rough pass at routing
    Everything can be improved a lot, and I don't have vias to ground on the
    top layer. The 3v3 line to the controller is also missing.
    [Neopixel_pico_arcade.kicad_pcb]
2021-10-05 Routes ground for LEDs and their decoupling capacitors
    [Neopixel_pico_arcade.kicad_pcb]
2021-10-05 Changes positions of the controller and USB connector
    This makes it easier to route the USB signal and also makes more sense
    since the NES connector and cable are pretty heavy and will probably be
    better bellow.
    [Neopixel_pico_arcade.kicad_pcb]
2021-10-05 Removes SWD header
    We will very likely not need it anyways since we have a USB connection
    for programming.
    [Neopixel_pico_arcade.kicad_pcb, Neopixel_pico_arcade.kicad_sch]
2021-10-05 Removes jumpers from schematics
    If we mix up clock and latch we can swap them in software
    [Neopixel_pico_arcade.kicad_sch]
2021-10-05 Reroutes NES controler lines
    [Neopixel_pico_arcade.kicad_pcb]
2021-10-05 Fixes pad entries for USB lines in TVS diodes
    [Neopixel_pico_arcade.kicad_pcb]
2021-10-05 Reorganizes power traces around USB connector
    [Neopixel_pico_arcade.kicad_pcb]
2021-10-05 Reorganizes some of the silkscreen designators
    [Neopixel_pico_arcade.kicad_pcb]
2021-10-06 Reroutes NES controller data lines
    [Neopixel_pico_arcade.kicad_pcb]
2021-10-06 Fixes most DRC errors and warnings
    There are still a few errors related to the USB-C connector footprint.
    [Neopixel_pico_arcade.kicad_pcb]
2021-10-06 Reorganizes data and power lines for NES controller
    [Neopixel_pico_arcade.kicad_pcb]
2021-10-06 Adds logo footprint to the board
    [Neopixel_pico_arcade.kicad_pcb]
2021-10-06 Adds revision number (1.0) and JLCPCB order number placeholder
    [Neopixel_pico_arcade.kicad_pcb]
2021-10-12 Adds interactive BOM generated by InteractiveHtmlBom
    https://github.com/openscopeproject/InteractiveHtmlBom
2021-10-17 Adds PCB 3D renders and Schematics PDF to the repo
2021-10-17 Removes footprint for NES controller since it's completely broken
